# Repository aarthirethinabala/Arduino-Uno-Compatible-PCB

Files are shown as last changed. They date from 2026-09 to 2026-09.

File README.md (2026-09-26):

# Arduino Uno-Compatible PCB
Custom Arduino Uno-compatible PCB designed in KiCad, including schematic design, component footprint assignment, PCB layout, routing, and 3D visualization.

## Project Status
Completed

## Overview
This project involved designing an Arduino Uno-compatible printed circuit board(PCB) from the schematic stage through PCB layout and design-rule checking.
The design was created in KiCad and includes the major components and connections required for an Arduino Uno-compatible board.

## Tools Used
- KiCad
- PCB Editor
- Schematic Editor
- 3D Viewer

## Board Features
- ATmega328P microcontroller
- ATmega16U2 USB interface
- USB-C connector
- DC barrel jack input
- 5V and 3.3V voltage regulation
- Reset switch
- LEDs and indicator components
- Crystal oscillators
- ESD protection
- Resistor networks
- Through-hole and SMD components
- Front and back copper routing
- Ground copper zones

## Design Process
The PCB was developed through the following stages:
1. Schematic design
2. Electrical Rules Check(ERC)
3. Footprint assignment
4. PCB component placement
5. Board outline creation
6. Track routing
7. Via placement
8. Copper zone creation
9. Design Rules Check(DRC)
10. 3D visualization

## Current Result
The schematic and PCB layout have been completed and checked using KiCad's ERC and DRC tools.
The final design includes routed connections, vias, copper zones, and the complete board outline.

## Project Images
### Root Schematic
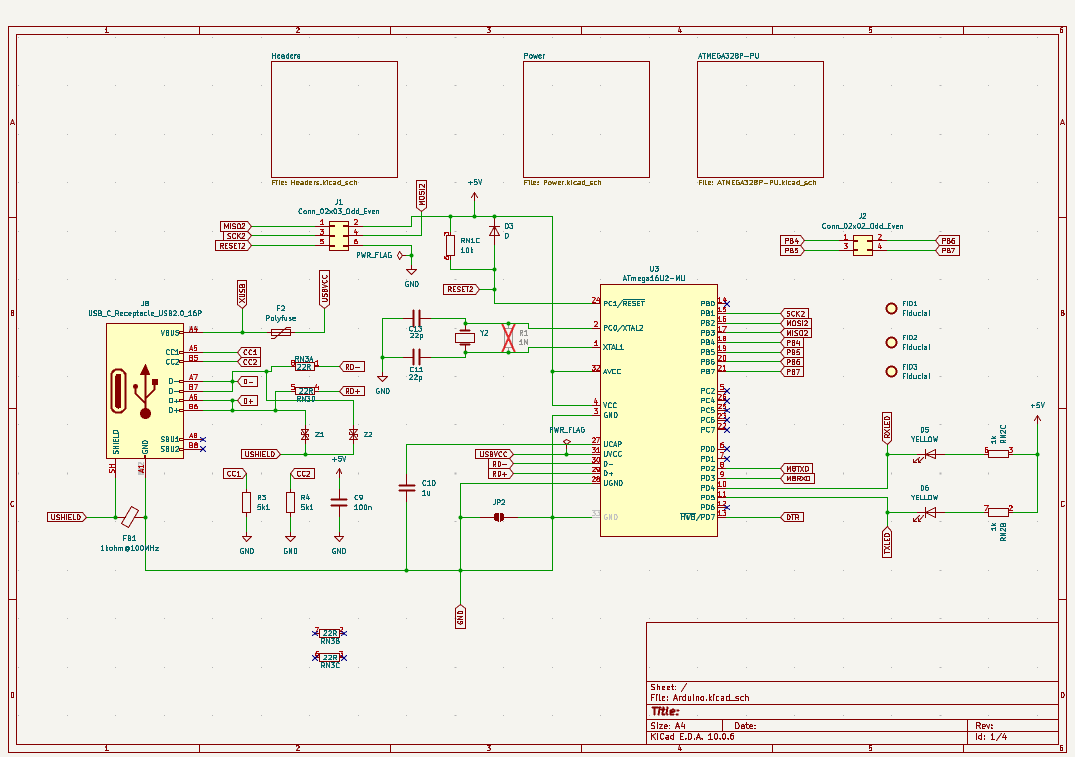
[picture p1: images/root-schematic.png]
Root schematic


### Headers Schematic
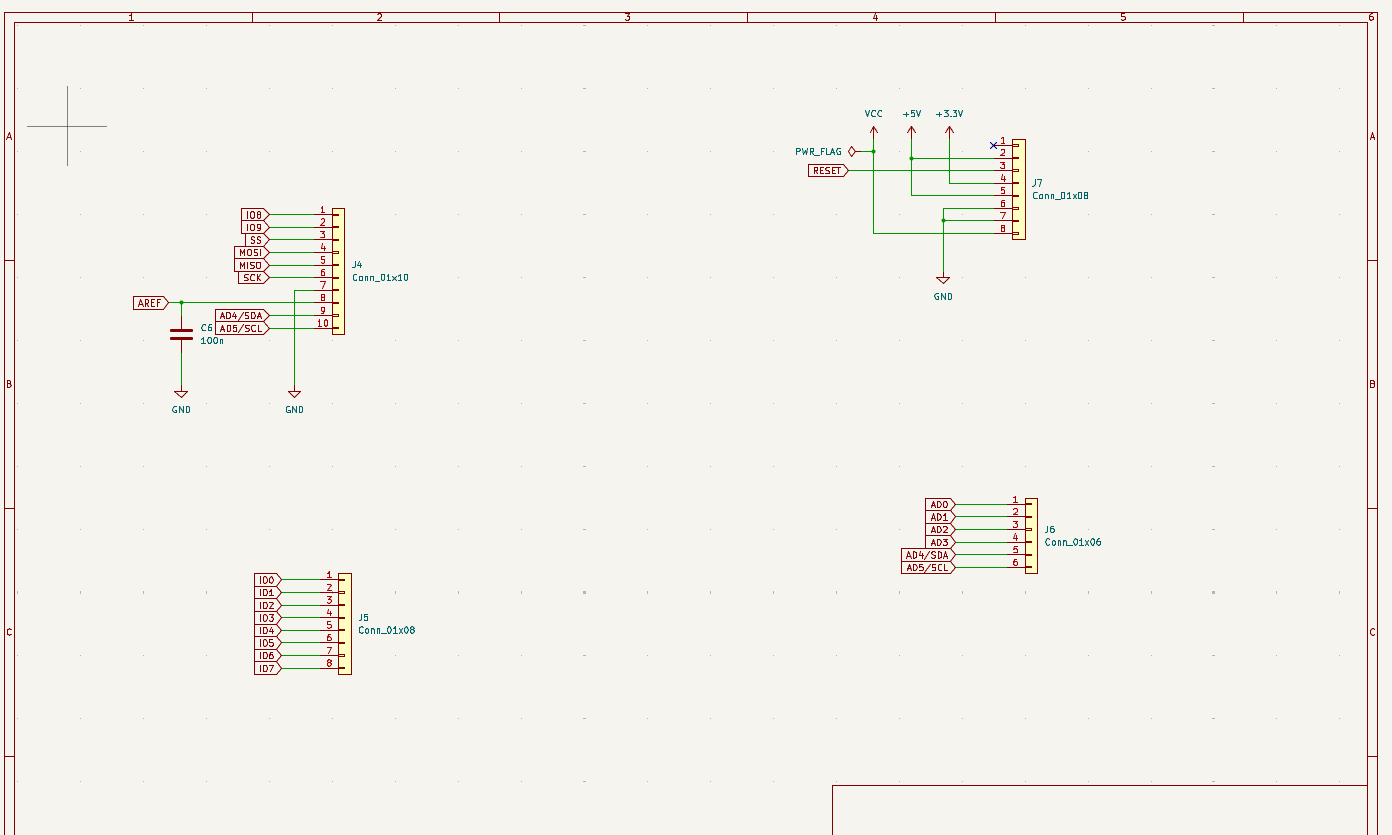
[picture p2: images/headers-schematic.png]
Headers schematic


### Power Schematic
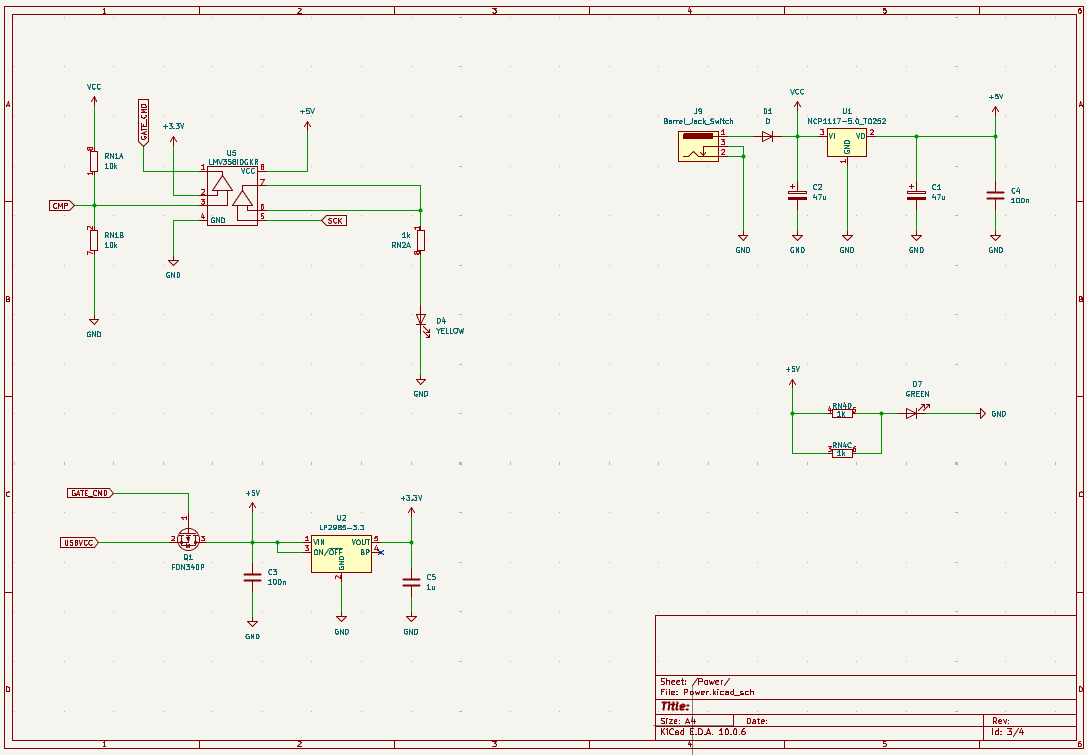
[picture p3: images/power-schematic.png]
Power schematic


### ATmega328P-PU Schematic
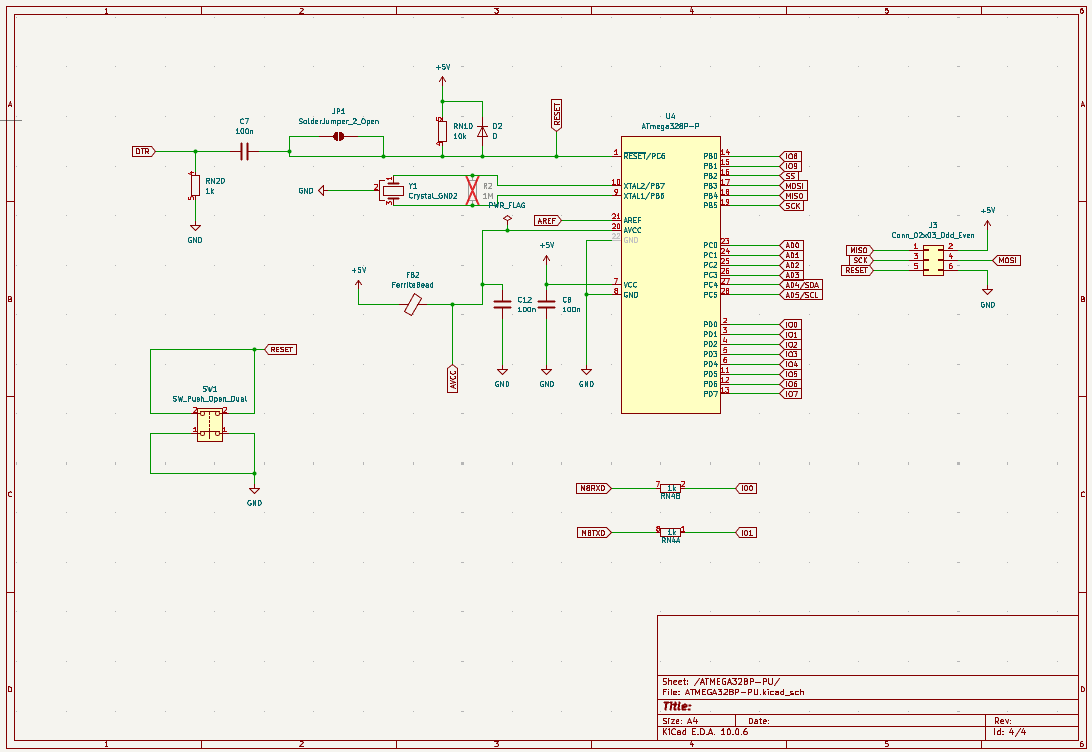
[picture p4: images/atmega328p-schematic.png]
ATmega328P schematic


### PCB Layout
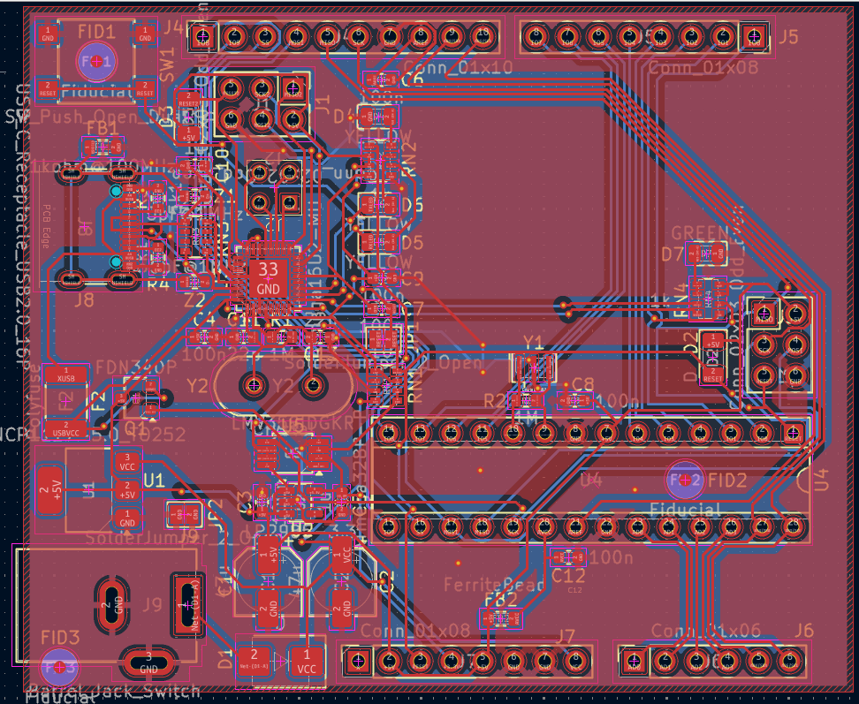
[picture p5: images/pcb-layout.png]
PCB layout


### 3D View
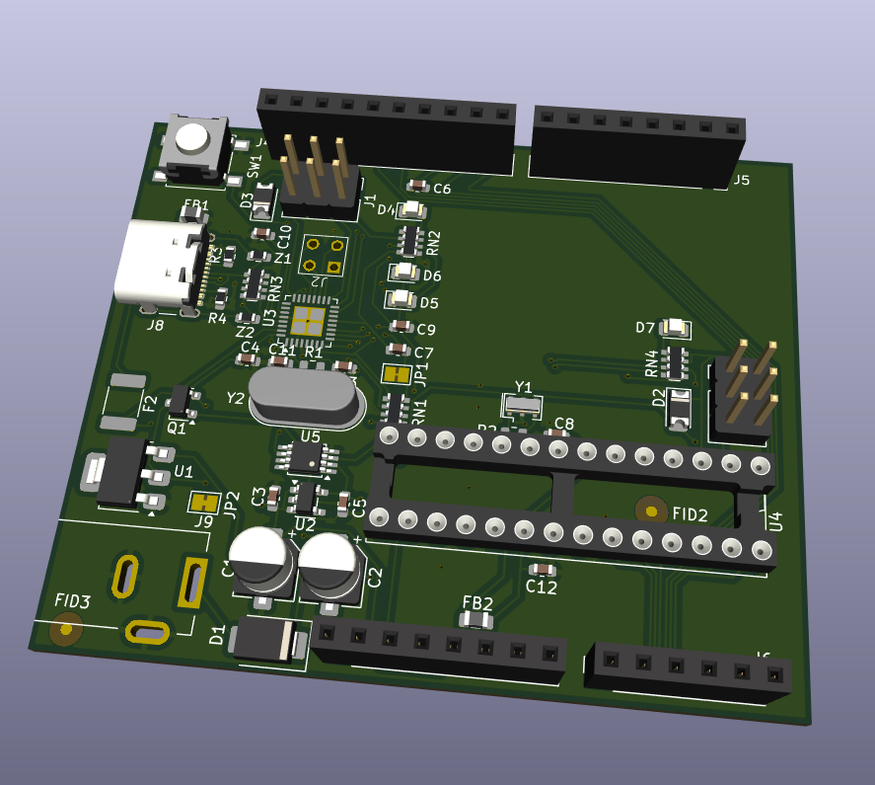
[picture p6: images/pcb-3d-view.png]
PCB 3D view


## What I Learned
- Schematic design and ERC checking
- Component footprint selection
- PCB component placement
- Routing on multiple copper layers
- Via placement
- Ground-plane/copper-zone creation
- PCB design-rule checking
- KiCad 3D visualization

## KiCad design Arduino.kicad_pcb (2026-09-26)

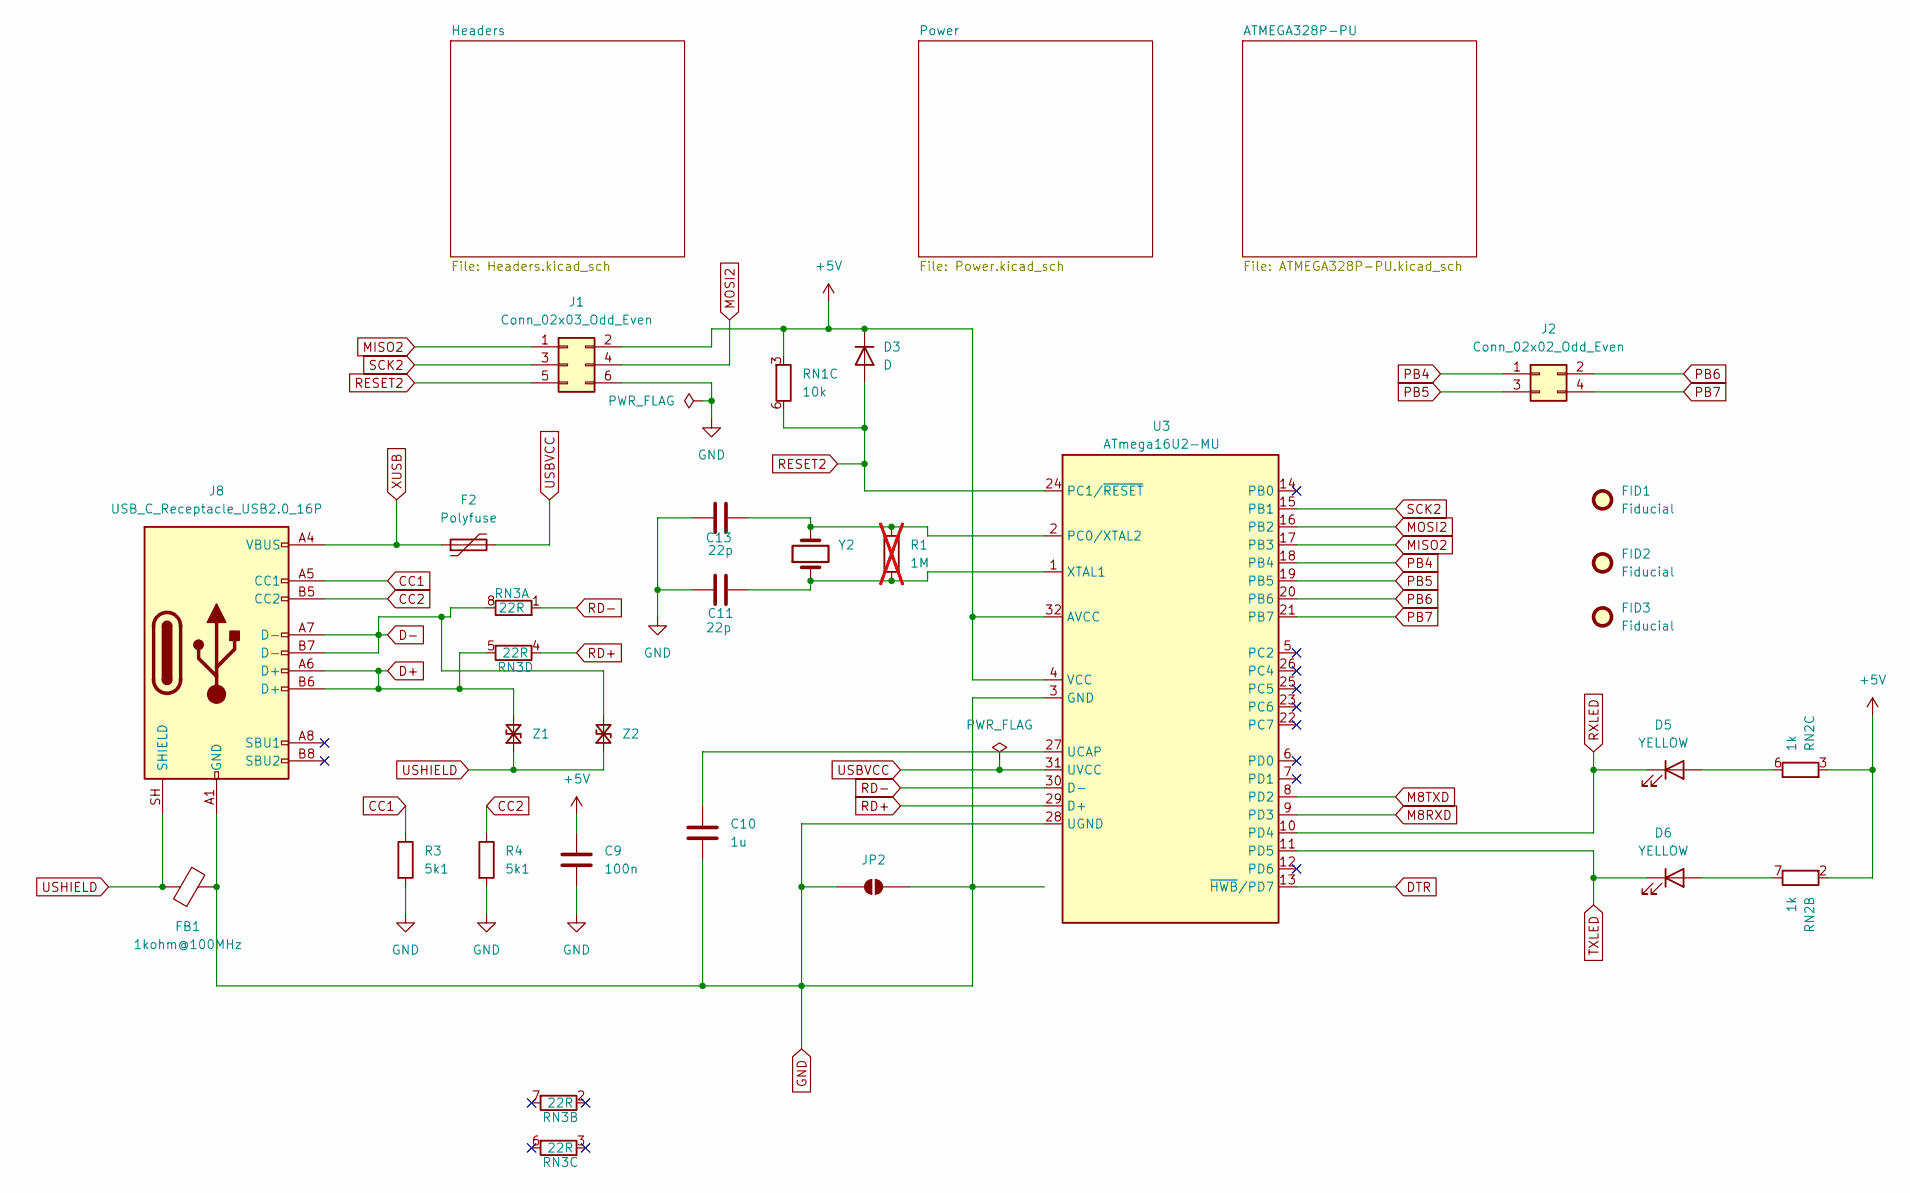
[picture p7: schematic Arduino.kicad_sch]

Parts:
C9: 100n; C_0603_1608Metric
C10: 1u; C_0603_1608Metric
C11, C13: 22p; C_0603_1608Metric
D3: D; D_1206_3216Metric
D5, D6: YELLOW; LED_0805_2012Metric
F2: Polyfuse; Fuse_1812_4532Metric_Pad1.30x3.40mm_HandSolder
FB1: 1kohm@100MHz; L_0805_2012Metric
FID1, FID2, FID3: Fiducial; Fiducial_1mm_Mask3mm
J1: Conn_02x03_Odd_Even; PinHeader_2x03_P2.54mm_Vertical
J2: Conn_02x02_Odd_Even; 02x02 tht hole
J8: USB_C_Receptacle_USB2.0_16P; USB_C_Receptacle_GCT_USB4105-xx-A_16P_TopMnt_Horizontal
JP2: SolderJumper_2_Open; SolderJumper-2_P1.3mm_Open_Pad1.0x1.5mm
R1: 1M; R_0603_1608Metric; not fitted
R3, R4: 5k1; R_0603_1608Metric
RN1: 10k; R_Array_Convex_4x0603
RN2: 1k; R_Array_Convex_4x0603
RN3: 22R; R_Array_Convex_4x0603
U3: ATmega16U2-MU; VQFN-32-1EP_5x5mm_P0.5mm_EP3.1x3.1mm
Y2: Crystal; Crystal_HC49-4H_Vertical
Z1, Z2: 5pF@1MHz; R_0603_1608Metric

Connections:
+5V: C9.1, D3.1 (K), J1.2, RN1.3, RN2.2, RN2.3, U3.4 (VCC), U3.32 (AVCC); also elsewhere on the board
CC1: J8.A5 (CC1), R3.1
CC2: J8.B5 (CC2), R4.1
D+: J8.A6 (D+), J8.B6 (D+), RN3.5, Z1.2 (A2)
D-: J8.A7 (D-), J8.B7 (D-), RN3.8 (R1.2), Z2.2 (A2)
DTR: U3.13 (~HWB/PD7); also elsewhere on the board
GND: C9.2, C10.2, C11.1, C13.1, FB1.2, J1.6, J8.A1 (GND), J8.A12 (GND), J8.B1 (GND), J8.B12 (GND), JP2.1 (A), JP2.2 (B), R3.2, R4.2, U3.3 (GND), U3.28 (UGND), U3.33 (GND); also elsewhere on the board
M8RXD: U3.9 (PD3); also elsewhere on the board
M8TXD: U3.8 (PD2); also elsewhere on the board
MISO2: J1.1, U3.17 (PB3)
MOSI2: J1.4, U3.16 (PB2)
unnamed: D5.2 (A), RN2.6 (R3.2)
unnamed: D6.2 (A), RN2.7 (R2.2)
unnamed: C13.2, R1.1, U3.2 (PC0/XTAL2), Y2.2
unnamed: C10.1, U3.27 (UCAP)
unnamed: C11.2, R1.2, U3.1 (XTAL1), Y2.1
PB4: J2.1, U3.18 (PB4)
PB5: J2.3, U3.19 (PB5)
PB6: J2.2, U3.20 (PB6)
PB7: J2.4, U3.21 (PB7)
RD+: RN3.4 (R4.2), U3.29 (D+)
RD-: RN3.1 (R1), U3.30 (D-)
RESET2: D3.2 (A), J1.5, RN1.6 (R3.2), U3.24 (PC1/~RESET)
RXLED: D5.1 (K), U3.10 (PD4)
SCK2: J1.3, U3.15 (PB1)
TXLED: D6.1 (K), U3.11 (PD5)
USBVCC: F2.2, U3.31 (UVCC); also elsewhere on the board
USHIELD: FB1.1, J8.SH (SHIELD), Z1.1 (A1), Z2.1 (A1)
XUSB: F2.1, J8.A4 (VBUS), J8.A9 (VBUS), J8.B4 (VBUS), J8.B9 (VBUS)

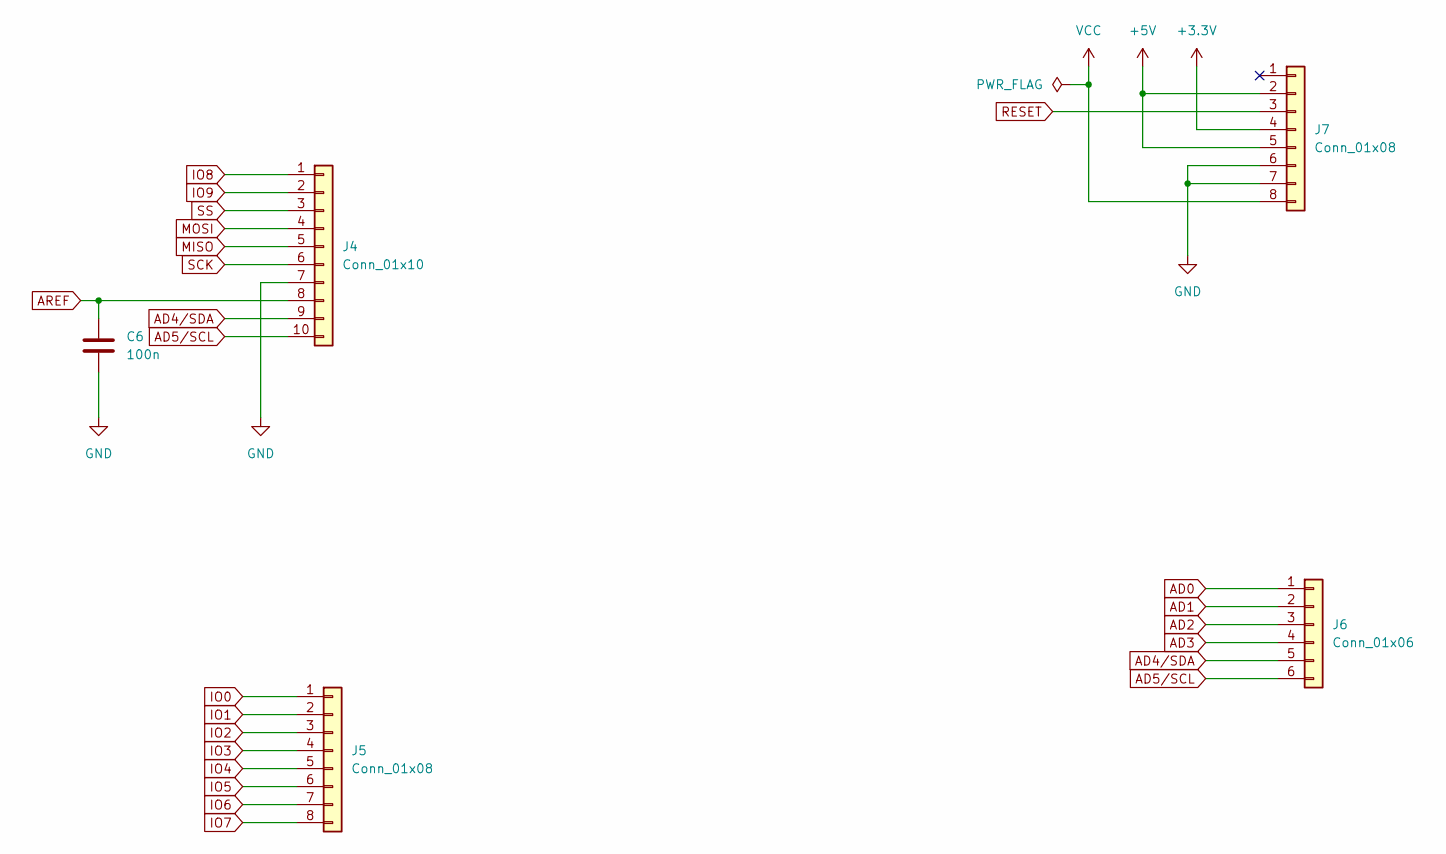
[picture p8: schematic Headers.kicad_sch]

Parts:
C6: 100n; C_0603_1608Metric
J4: Conn_01x10; PinSocket_1x10_P2.54mm_Vertical
J5, J7: Conn_01x08; PinSocket_1x08_P2.54mm_Vertical
J6: Conn_01x06; PinSocket_1x06_P2.54mm_Vertical

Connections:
+3.3V: J7.4; also elsewhere on the board
+5V: J7.2, J7.5; also elsewhere on the board
AD0: J6.1; also elsewhere on the board
AD1: J6.2; also elsewhere on the board
AD2: J6.3; also elsewhere on the board
AD3: J6.4; also elsewhere on the board
AD4/SDA: J4.9, J6.5; also elsewhere on the board
AD5/SCL: J4.10, J6.6; also elsewhere on the board
AREF: C6.1, J4.8; also elsewhere on the board
GND: C6.2, J4.7, J7.6, J7.7; also elsewhere on the board
IO0: J5.1; also elsewhere on the board
IO1: J5.2; also elsewhere on the board
IO2: J5.3; also elsewhere on the board
IO3: J5.4; also elsewhere on the board
IO4: J5.5; also elsewhere on the board
IO5: J5.6; also elsewhere on the board
IO6: J5.7; also elsewhere on the board
IO7: J5.8; also elsewhere on the board
IO8: J4.1; also elsewhere on the board
IO9: J4.2; also elsewhere on the board
MISO: J4.5; also elsewhere on the board
MOSI: J4.4; also elsewhere on the board
RESET: J7.3; also elsewhere on the board
SCK: J4.6; also elsewhere on the board
SS: J4.3; also elsewhere on the board
VCC: J7.8; also elsewhere on the board

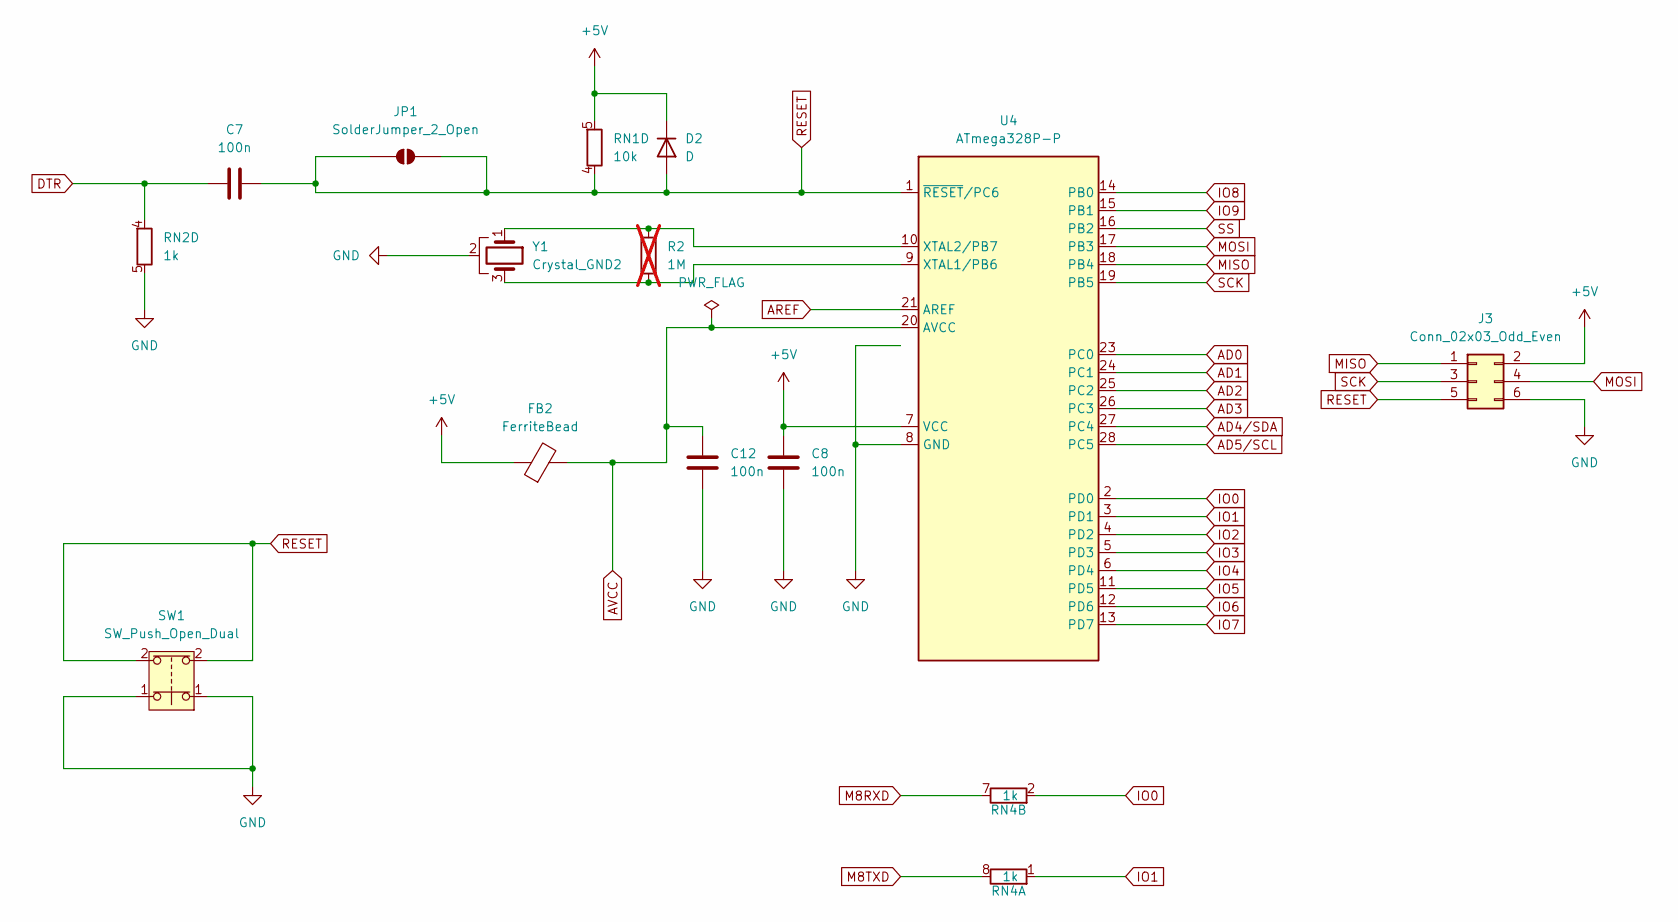
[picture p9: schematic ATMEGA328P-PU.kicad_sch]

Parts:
C7, C8, C12: 100n; C_0603_1608Metric
D2: D; D_1206_3216Metric
FB2: FerriteBead; L_0805_2012Metric
J3: Conn_02x03_Odd_Even; PinHeader_2x03_P2.54mm_Vertical
JP1: SolderJumper_2_Open; SolderJumper-2_P1.3mm_Open_Pad1.0x1.5mm
R2: 1M; R_0603_1608Metric; not fitted
RN1: 10k; R_Array_Convex_4x0603
RN2, RN4: 1k; R_Array_Convex_4x0603
SW1: SW_Push_Open_Dual; SW_SPST_B3S-1000
U4: ATmega328P-P; DIP-28_W7.62mm_Socket
Y1: Crystal_GND2; Resonator_SMD_Murata_CSTxExxV-3Pin_3.0x1.1mm

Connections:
+5V: C8.1, D2.1 (K), FB2.1, J3.2, RN1.5, U4.7 (VCC); also elsewhere on the board
AD0: U4.23 (PC0); also elsewhere on the board
AD1: U4.24 (PC1); also elsewhere on the board
AD2: U4.25 (PC2); also elsewhere on the board
AD3: U4.26 (PC3); also elsewhere on the board
AD4/SDA: U4.27 (PC4); also elsewhere on the board
AD5/SCL: U4.28 (PC5); also elsewhere on the board
AREF: U4.21 (AREF); also elsewhere on the board
AVCC: C12.1, FB2.2, U4.20 (AVCC)
DTR: C7.1, RN2.4 (R1); also elsewhere on the board
GND: C8.2, C12.2, J3.6, RN2.5 (R4.2), SW1.1, U4.8 (GND), U4.22 (GND), Y1.2; also elsewhere on the board
IO0: RN4.2, U4.2 (PD0); also elsewhere on the board
IO1: RN4.1 (R1), U4.3 (PD1); also elsewhere on the board
IO2: U4.4 (PD2); also elsewhere on the board
IO3: U4.5 (PD3); also elsewhere on the board
IO4: U4.6 (PD4); also elsewhere on the board
IO5: U4.11 (PD5); also elsewhere on the board
IO6: U4.12 (PD6); also elsewhere on the board
IO7: U4.13 (PD7); also elsewhere on the board
IO8: U4.14 (PB0); also elsewhere on the board
IO9: U4.15 (PB1); also elsewhere on the board
M8RXD: RN4.7 (R2.2); also elsewhere on the board
M8TXD: RN4.8 (R1.2); also elsewhere on the board
MISO: J3.1, U4.18 (PB4); also elsewhere on the board
MOSI: J3.4, U4.17 (PB3); also elsewhere on the board
unnamed: R2.2, U4.9 (XTAL1/PB6), Y1.3
unnamed: R2.1, U4.10 (XTAL2/PB7), Y1.1
RESET: C7.2, D2.2 (A), J3.5, JP1.1 (A), JP1.2 (B), RN1.4 (R4.2), SW1.2, U4.1 (~RESET/PC6); also elsewhere on the board
SCK: J3.3, U4.19 (PB5); also elsewhere on the board
SS: U4.16 (PB2); also elsewhere on the board

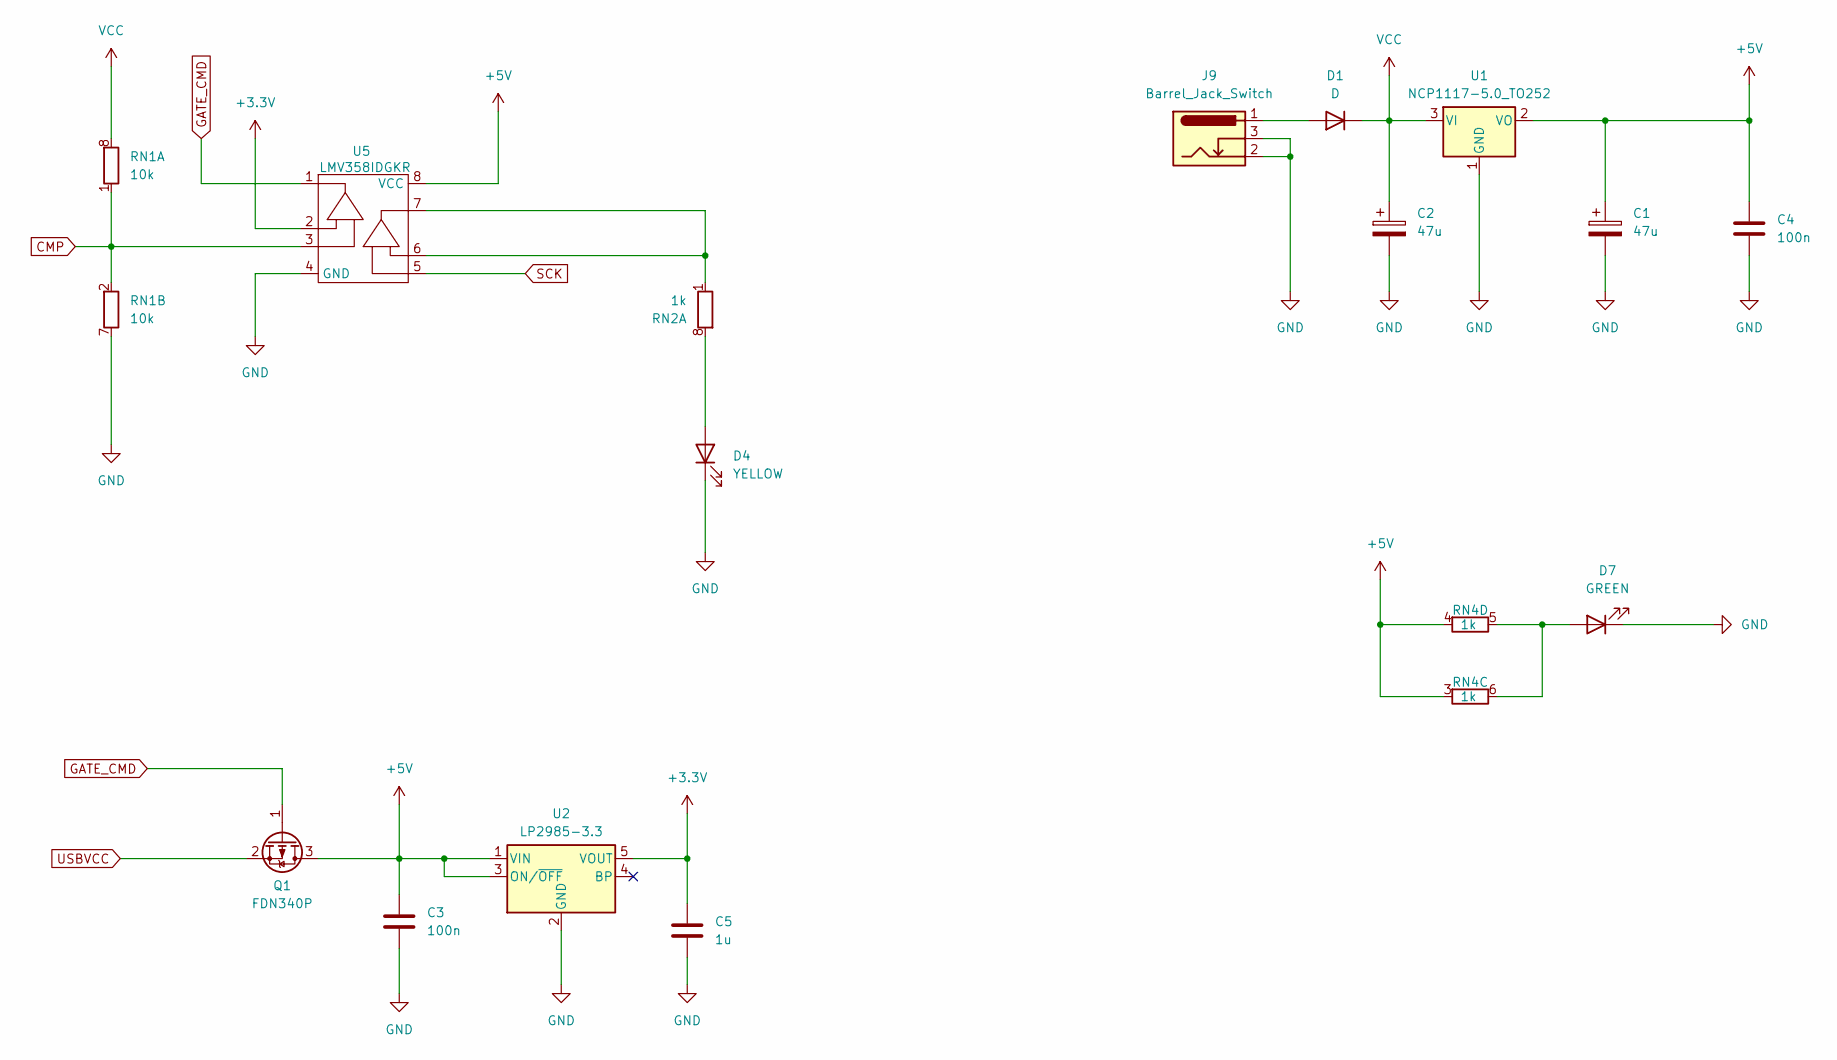
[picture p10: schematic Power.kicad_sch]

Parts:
C1, C2: 47u; CP_Elec_5x5.4
C3, C4: 100n; C_0603_1608Metric
C5: 1u; C_0603_1608Metric
D1: D; D_SMB
D4: YELLOW; LED_0805_2012Metric
D7: GREEN; LED_0805_2012Metric
J9: Barrel_Jack_Switch; BarrelJack_Kycon_KLDX-0202-xC_Horizontal
Q1: FDN340P; SC-59
RN1: 10k; R_Array_Convex_4x0603
RN2, RN4: 1k; R_Array_Convex_4x0603
U1: NCP1117-5.0_TO252; SOT-223-3_TabPin2
U2: LP2985-3.3; SOT-23-5
U5: LMV358IDGKR; MSOP-8_3x3mm_P0.65mm

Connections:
+3.3V: C5.1, U2.5 (VOUT), U5.2; also elsewhere on the board
+5V: C1.1, C3.1, C4.1, Q1.3 (D), RN4.3, RN4.4, U1.2 (VO), U2.1 (VIN), U2.3 (ON/~OFF), U5.8 (VCC); also elsewhere on the board
CMP: RN1.1 (R1.2), RN1.2, U5.3
GATE_CMD: Q1.1 (G), U5.1
GND: C1.2, C2.2, C3.2, C4.2, C5.2, D4.1 (K), D7.1 (K), J9.2, J9.3, RN1.7 (R2.2), U1.1 (GND), U2.2 (GND), U5.4 (GND); also elsewhere on the board
unnamed: D1.2 (A), J9.1
unnamed: D4.2 (A), RN2.8
unnamed: D7.2 (A), RN4.5 (R4.2), RN4.6 (R3.2)
unnamed: RN2.1 (R1.2), U5.6, U5.7
SCK: U5.5; also elsewhere on the board
USBVCC: Q1.2 (S); also elsewhere on the board
VCC: C2.1, D1.1 (K), RN1.8 (R1), U1.3 (VI); also elsewhere on the board

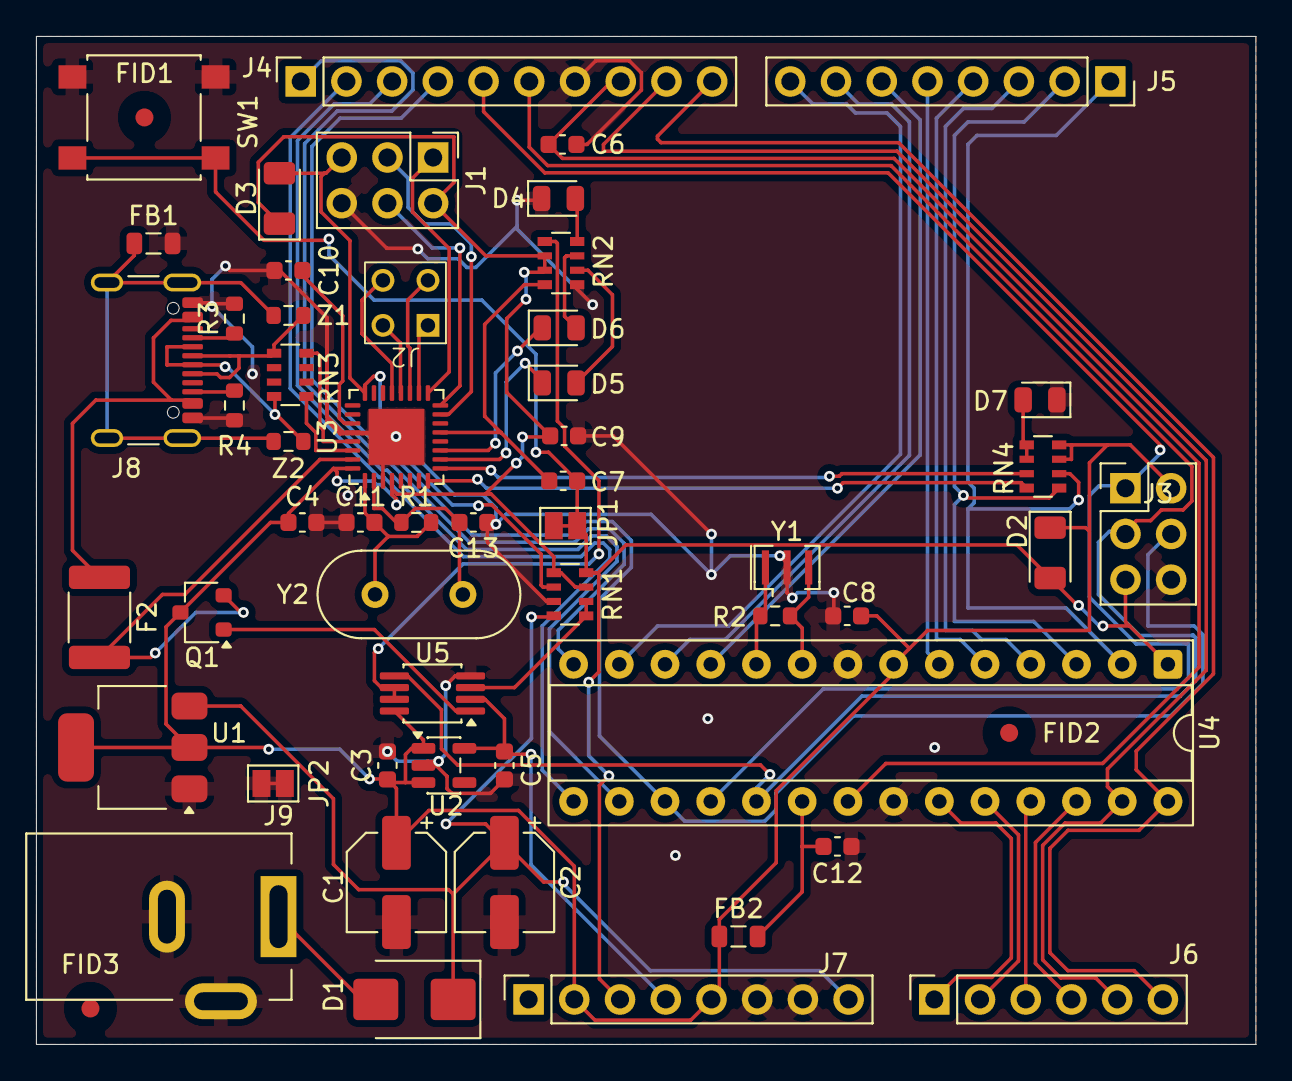
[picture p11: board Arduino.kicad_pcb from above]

Board: 2 copper layers, 67.8 x 56.0 mm, 56 parts (0 on the bottom side), 62 nets.

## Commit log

2026-09-26 Update README with detailed project overview
    Expanded project details and added sections on tools used, board features, design process, current result, project images, and lessons learned.
2026-09-26 Rename Arduino 3D.png to pcb-3d-view.png
2026-09-26 Rename Arduino root page.png to root-schematic.png
2026-09-26 Rename Arduino power.png to power-schematic.png
2026-09-26 Rename Arduino headers.png to headers-schematic.png
2026-09-26 Rename Arduino PCB.png to pcb-layout.png
2026-09-26 Rename Arduino ATMEGA328P-PU.png to atmega328p-schematic.png
2026-09-26 Update README with project images and schematics
    Added images of schematics and PCB layout to README.
